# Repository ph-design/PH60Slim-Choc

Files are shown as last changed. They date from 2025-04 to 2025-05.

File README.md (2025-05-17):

### English Ver. | [中文](README-ZH.md)
---
# PH60 Slim-Choc  


**PH60 Slim-Choc is a 60% ANSI layout low-profile mechanical keyboard designed for portability and customization.**  
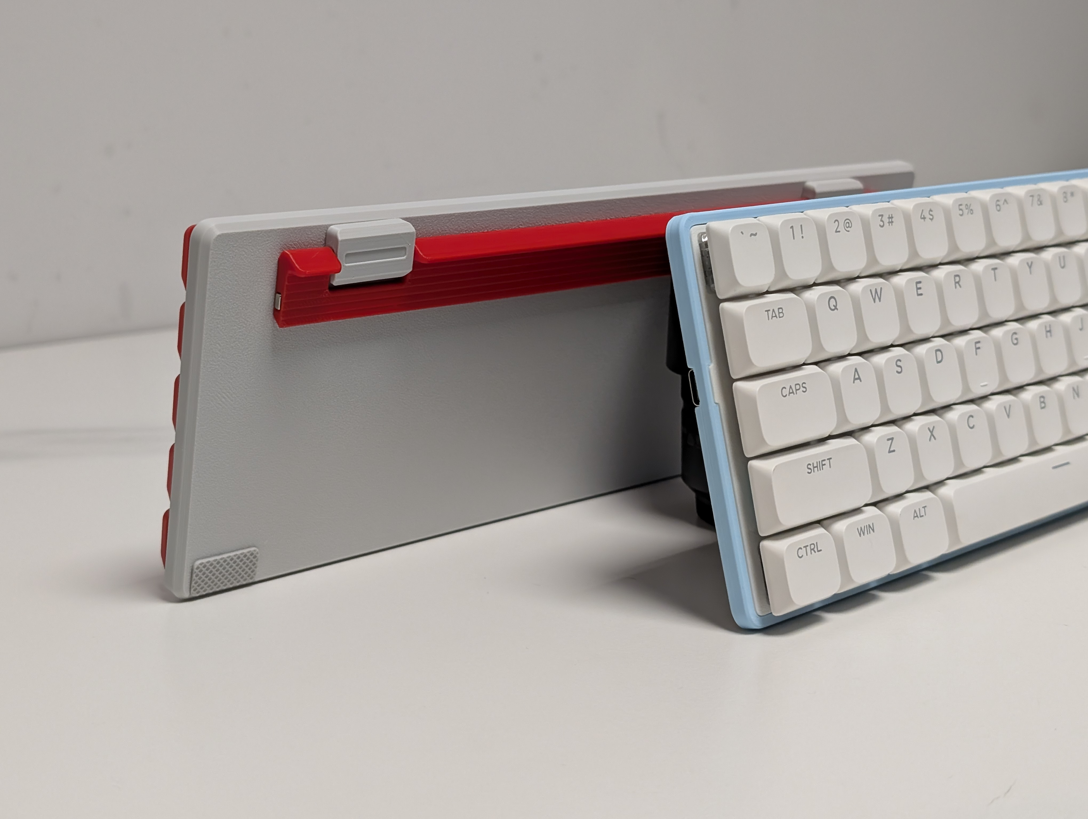
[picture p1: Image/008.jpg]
PH60Slim-Choc main frame


---

## Table of Contents
- [PH60 Slim-Choc](#ph60-slim-choc)
  - [Table of Contents](#table-of-contents)
  - [Features](#features)
  - [Required Components](#required-components)
  - [Printing Guide](#printing-guide)
    - [Case](#case)
    - [Keycaps](#keycaps)
  - [Assembly Guide](#assembly-guide)
  - [Firmware \& Configuration (WIP)](#firmware--configuration-wip)
    - [QMK/VIA Setup](#qmkvia-setup)
  - [Contributing](#contributing)
  - [FAQ](#faq)
  - [Special thanks](#special-thanks)
  - [Links](#links)
  - [License](#license)
  - [Changelog](#changelog)

---

## Features
+ 📏 **Ultra-Slim Design**: 7mm physical front height (4.5mm visual)
+ 🧲 **Adjustable Typing Angle**: Magnetic 2-step foldable footstand (5° and 10°)
+ 💻 **Laptop-Friendly**: Side-out USB-C for seamless laptop integration
+ 🔅 **Hotswap Ready**: Kailh Choc V1/V2 low-profile switches
+ 🖨️ **Easy Manufacturing**: Optimized for 3D printing/CNC
+ ⚡ **QMK & VIA Support**: Fully programmable with open-source firmware

---

## Required Components
| Part Name | Amount | Remark |
|---|---|---|
| PH60Slim-Choc PCB | 1 | Purchase in our Taobao Store (optional) |
| M2×2×3 Heat-Set Inserts | 10 | For securing case components |
| M2×3 Flat Head Screws | 4 | Footstand mounting |
| M2×5 Flat Head Screws | 6 | Case assembly |
| 20×10×0.5mm Ferrous Plate | 1 | Magnet alignment |
| 10×4×2mm N52 Magnet | 1 | Footstand retention |
| Low-Profile Stabilizers | 5 | 4×2u + 1×6.25u |
| Kailh Choc Switches | 61 | Compatible with Choc V1/V2 |
| Case Components | 1 set  | Includes bottom case, footstand, plate |
| Keycaps | 61 | DSA height recommended |

---

## Printing Guide
Slim-Choc components are optimized for Bambu Lab printers. However, they can also be printed with other printers by adjusting some of the parameters as follow:
### Case
- **Printing Profile**: [MakerWorld](https://makerworld.com/en/models/1361888)
- **Filament**: PLA 
- **Layer Height**: 0.16mm (0.2mm acceptable)
- **Walls**: 4 loops, Arachne wall generator
- **Infill**: 100% 
- **Supports**: Tree (auto)

### Keycaps
- **Printing Profile**: Follow [MakerWorld](https://makerworld.com/en/models/1394378)
- **Filament**: PETG

---

## Assembly Guide
1. **Heat-Set Inserts**  
   - Use soldering iron at 200°C to install inserts (8 in case, 4 in footstand).  
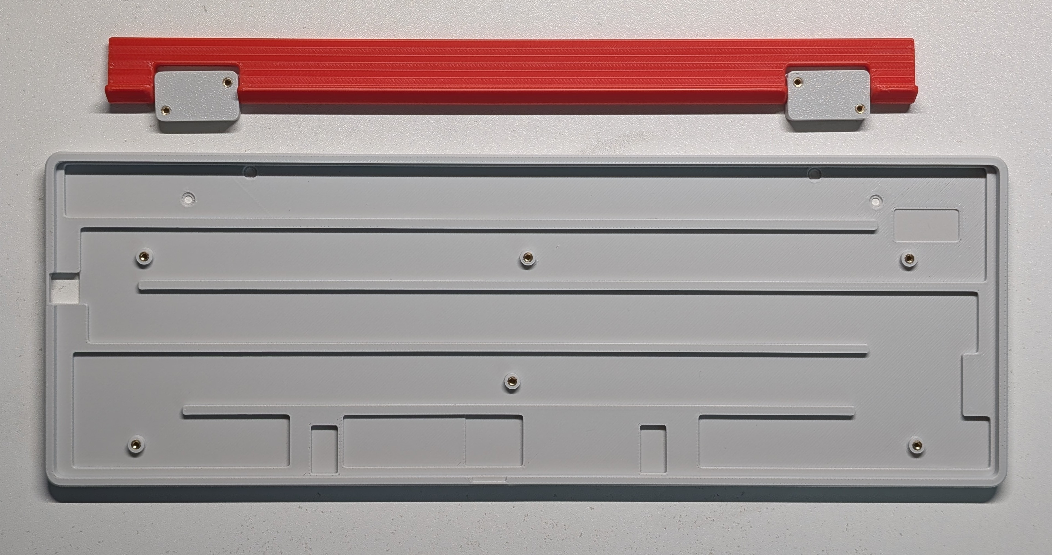
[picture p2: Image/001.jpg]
Heat insert installation
   

2. **Magnet Installation**  
   - Press-fit N52 magnet into footstand recess.  
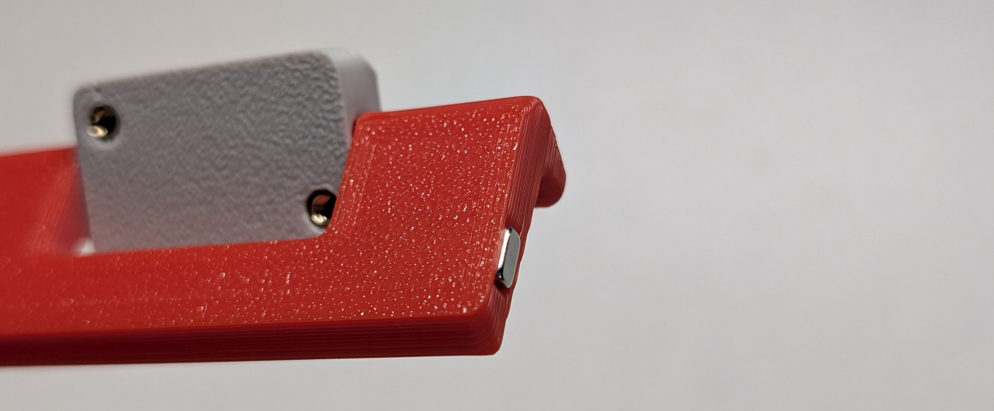
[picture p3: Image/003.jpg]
Magnet placement
   

3. **Footstand Assembly**  
   - Secure with M2×3 screws. Ensure smooth angular adjustment.  
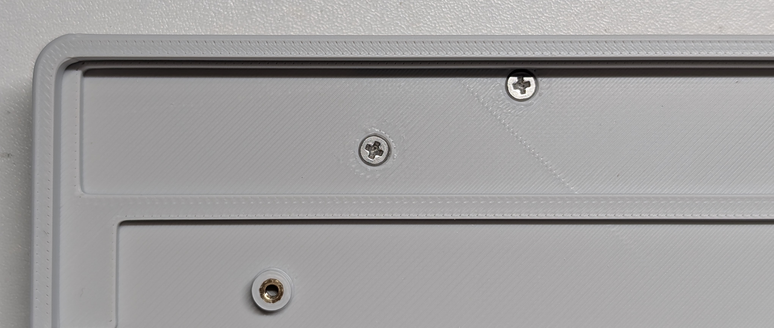
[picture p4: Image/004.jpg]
Footstand screws
   

4. **Ferrous Plate Attachment**  
   - Apply glue and insert an iron piece into the case. 
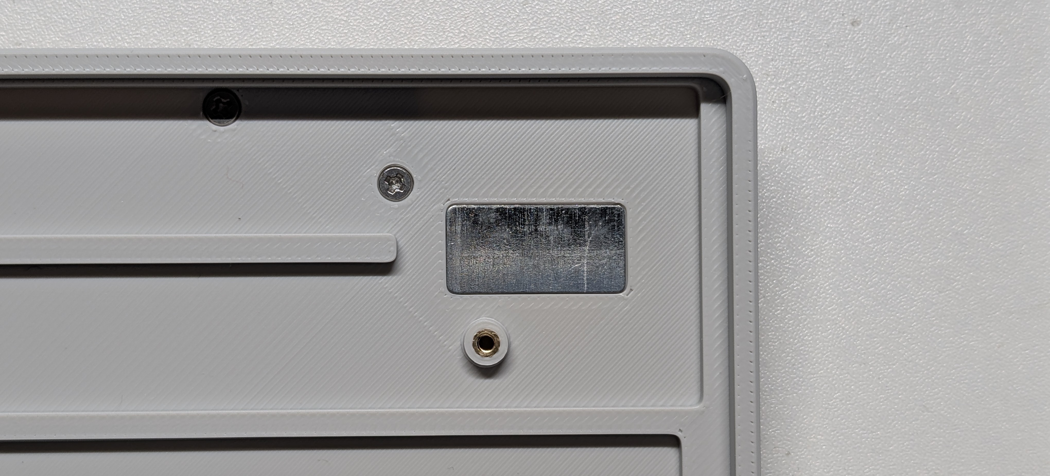
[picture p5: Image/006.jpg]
Steel plate installation
   

5. **Anti-Slip Pads**  
   - Apply silicone pads to case corners.  
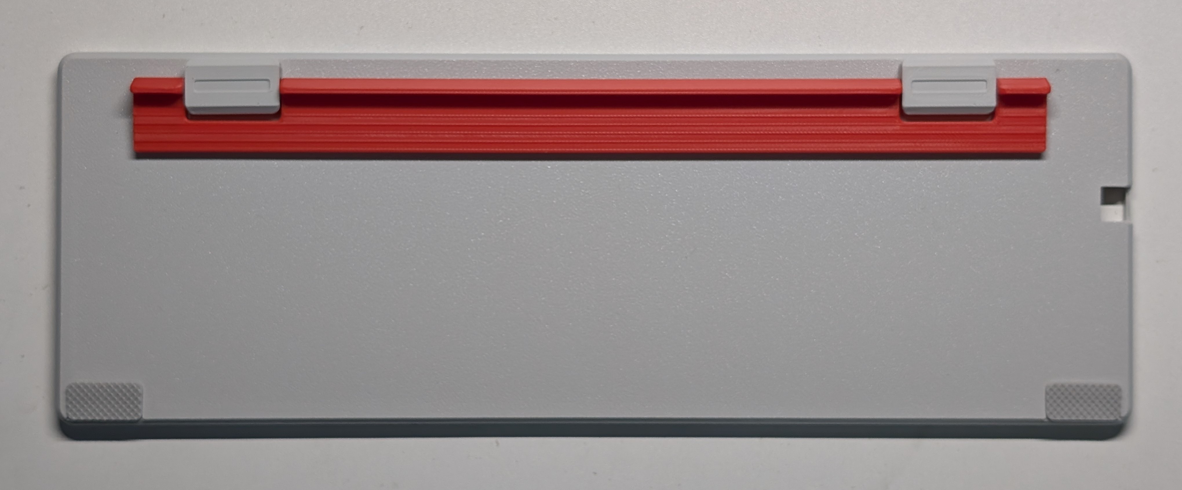
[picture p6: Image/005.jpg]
Silicone pads
   

6. **PCB & Plate Integration**  
   - Align plate with PCB, insert stabilizers and switches partially, then mount to case with M2×5 screws (torque evenly).  

7. **Final Assembly**  
   - Fully seat switches, test connectivity, then install keycaps.
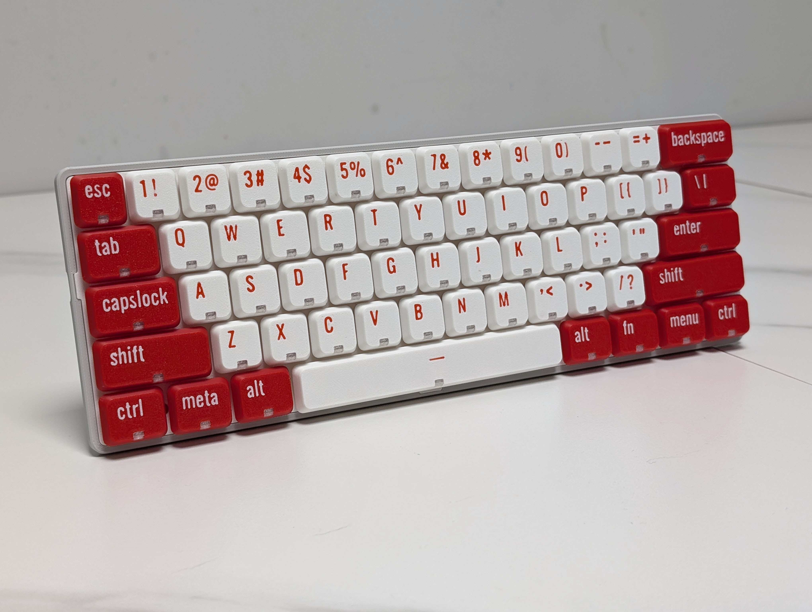
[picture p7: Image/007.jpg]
PCB assembly
   

---

## Firmware & Configuration (WIP)
### QMK/VIA Setup
1. **Compile from Source**:  
   ```bash
   qmk compile -kb phdesign/ph60slim_choc -km via
   ```
2. **Flashing**:  
  Shorten the boot perforations around the space with a metal object, plug in the USB cable, and drag the firmware into the USB drive that appears.

1. **Keymap Editor**:  
   Configure directly via [VIA Web](https://usevia.app/)

---

## Contributing
We welcome contributions! Please:  
1. Fork the repository
2. Create a feature branch
3. Submit PR with detailed description  

**Guidelines**:  
- Follow QMK coding standards for firmware  
- Include STEP files for hardware modifications  
- A dedicated documentation website will be available soon.

---

## FAQ
**Q: What switches can I use?**  
A: **ONLY** Kailh Choc switch, not Gateron or Cherry.

**Q: Where can I get the special stabilizer?**  
A: It can be found on Taobao, or modify the mounting plate to use Kailh official stabilizer (Not verified).

**Q: USB-C port not detected?**  
A: Ensure proper alignment of side-out connector with case cutout.

**Q: Recommended keycap?**  
A: Special low-profile keycaps are required. You can try our 3D-printed keycaps alternatively.

---

## Special thanks
- QMK Community for firmware support
- Bambu Lab for 3D printing support

---

## Links
- [GitHub Repository](https://github.com/ph-design/PH60Slim-Choc) 
- [Discord Community](https://discord.gg/8UfQXcefPH)
- [Build Video (Bilibili)](https://www.bilibili.com/video/BV1Te5VzBEiK/)
- [Purchase link (Taobao)](https://shop268559013.taobao.com/)
- [3D Printing Profiles](https://makerworld.com/en/@M_Altmann)
- [Official Website](https://phdesign.cc)

---

## License
This project is licensed under the [CC BY-NC-SA 4.0](https://creativecommons.org/licenses/by-nc-sa/4.0/) license.

---

## Changelog
- **2025-05-10**: Initial release.

---

*Project maintained by ph.design Released: 2025.05 


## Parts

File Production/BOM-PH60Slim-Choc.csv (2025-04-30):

Comment | Designator | Footprint | LCSC | Quantity
Choc_V1V2 | S20 | SW_Hotswap_Kailh_Choc_V1V2_Plated_1.00u |  | 1
Choc_V1V2 | S19 | SW_Hotswap_Kailh_Choc_V1V2_Plated_1.00u |  | 1
Choc_V1V2 | S47 | SW_Hotswap_Kailh_Choc_V1V2_Plated_1.00u |  | 1
Choc_V1V2 | S4 | SW_Hotswap_Kailh_Choc_V1V2_Plated_1.00u |  | 1
Choc_V1V2 | S7 | SW_Hotswap_Kailh_Choc_V1V2_Plated_1.00u |  | 1
Choc_V1V2 | S12 | SW_Hotswap_Kailh_Choc_V1V2_Plated_1.00u |  | 1
Choc_V1V2 | S62 | SW_Hotswap_Kailh_Choc_V1V2_Plated_1.25u |  | 1
Choc_V1V2 | S3 | SW_Hotswap_Kailh_Choc_V1V2_Plated_1.00u |  | 1
MountingHole | H4 | MountingHole_2.2mm_M2 |  | 1
Choc_V1V2 | S15 | SW_Hotswap_Kailh_Choc_V1V2_Plated_1.50u |  | 1
Choc_V1V2 | S25 | SW_Hotswap_Kailh_Choc_V1V2_Plated_1.00u |  | 1
Choc_V1V2 | S1 | SW_Hotswap_Kailh_Choc_V1V2_Plated_1.00u |  | 1
Choc_V1V2 | S9 | SW_Hotswap_Kailh_Choc_V1V2_Plated_1.00u |  | 1
Choc_V1V2 | S23 | SW_Hotswap_Kailh_Choc_V1V2_Plated_1.00u |  | 1
Choc_V1V2 | S57 | SW_Hotswap_Kailh_Choc_V1V2_Plated_1.25u |  | 1
Choc_V1V2 | S14 | SW_Hotswap_Kailh_Choc_V1V2_Plated_2.00u |  | 1
Choc_V1V2 | S61 | SW_Hotswap_Kailh_Choc_V1V2_Plated_1.25u |  | 1
Choc_V1V2 | S16 | SW_Hotswap_Kailh_Choc_V1V2_Plated_1.00u |  | 1
Choc_V1V2 | S24 | SW_Hotswap_Kailh_Choc_V1V2_Plated_1.00u |  | 1
Choc_V1V2 | S31 | SW_Hotswap_Kailh_Choc_V1V2_Plated_1.00u |  | 1
Choc_V1V2 | S33 | SW_Hotswap_Kailh_Choc_V1V2_Plated_1.00u |  | 1
Choc_V1V2 | S34 | SW_Hotswap_Kailh_Choc_V1V2_Plated_1.00u |  | 1
Choc_V1V2 | S46 | SW_Hotswap_Kailh_Choc_V1V2_Plated_1.00u |  | 1
MountingHole | H5 | MountingHole_2.2mm_M2 |  | 1
Choc_V1V2 | S50 | SW_Hotswap_Kailh_Choc_V1V2_Plated_1.00u |  | 1
Choc_V1V2 | S22 | SW_Hotswap_Kailh_Choc_V1V2_Plated_1.00u |  | 1
MountingHole | H1 | MountingHole_2.2mm_M2 |  | 1
Choc_V1V2 | S27 | SW_Hotswap_Kailh_Choc_V1V2_Plated_1.00u |  | 1
Choc_V1V2 | S58 | SW_Hotswap_Kailh_Choc_V1V2_Plated_1.25u |  | 1
Choc_V1V2 | S8 | SW_Hotswap_Kailh_Choc_V1V2_Plated_1.00u |  | 1
Choc_V1V2 | S63 | SW_Hotswap_Kailh_Choc_V1V2_Plated_1.25u |  | 1
Choc_V1V2 | S37 | SW_Hotswap_Kailh_Choc_V1V2_Plated_1.00u |  | 1
Choc_V1V2 | S21 | SW_Hotswap_Kailh_Choc_V1V2_Plated_1.00u |  | 1
Choc_V1V2 | S11 | SW_Hotswap_Kailh_Choc_V1V2_Plated_1.00u |  | 1
Choc_V1V2 | S52 | SW_Hotswap_Kailh_Choc_V1V2_Plated_1.00u |  | 1
Choc_V1V2 | S30 | SW_Hotswap_Kailh_Choc_V1V2_Plated_1.00u |  | 1
Choc_V1V2 | S38 | SW_Hotswap_Kailh_Choc_V1V2_Plated_1.00u |  | 1
Choc_V1V2 | S35 | SW_Hotswap_Kailh_Choc_V1V2_Plated_1.00u |  | 1
Choc_V1V2 | S39 | SW_Hotswap_Kailh_Choc_V1V2_Plated_1.00u |  | 1
Choc_V1V2 | S48 | SW_Hotswap_Kailh_Choc_V1V2_Plated_1.00u |  | 1
Choc_V1V2 | S18 | SW_Hotswap_Kailh_Choc_V1V2_Plated_1.00u |  | 1
Choc_V1V2 | S41-2 | SW_Hotswap_Kailh_Choc_V1V2_Plated_2.25u |  | 1
Choc_V1V2 | S45 | SW_Hotswap_Kailh_Choc_V1V2_Plated_1.00u |  | 1
Choc_V1V2 | S13 | SW_Hotswap_Kailh_Choc_V1V2_Plated_1.00u |  | 1
Choc_V1V2 | S26 | SW_Hotswap_Kailh_Choc_V1V2_Plated_1.00u |  | 1
Choc_V1V2 | S5 | SW_Hotswap_Kailh_Choc_V1V2_Plated_1.00u |  | 1
Choc_V1V2 | S17 | SW_Hotswap_Kailh_Choc_V1V2_Plated_1.00u |  | 1
Choc_V1V2 | S32 | SW_Hotswap_Kailh_Choc_V1V2_Plated_1.00u |  | 1
Choc_V1V2 | S55-2 | SW_Hotswap_Kailh_Choc_V1V2_Plated_2.75u |  | 1
Choc_V1V2 | S36 | SW_Hotswap_Kailh_Choc_V1V2_Plated_1.00u |  | 1
Choc_V1V2 | S49 | SW_Hotswap_Kailh_Choc_V1V2_Plated_1.00u |  | 1
Choc_V1V2 | S60 | SW_Hotswap_Kailh_Choc_V1V2_Plated_6.25u |  | 1
Choc_V1V2 | S53 | SW_Hotswap_Kailh_Choc_V1V2_Plated_1.00u |  | 1
Choc_V1V2 | S10 | SW_Hotswap_Kailh_Choc_V1V2_Plated_1.00u |  | 1
MountingHole | H6 | MountingHole_2.2mm_M2 |  | 1
Choc_V1V2 | S59 | SW_Hotswap_Kailh_Choc_V1V2_Plated_1.25u |  | 1
Choc_V1V2 | S54 | SW_Hotswap_Kailh_Choc_V1V2_Plated_1.00u |  | 1
Choc_V1V2 | S51 | SW_Hotswap_Kailh_Choc_V1V2_Plated_1.00u |  | 1
Choc_V1V2 | S28-2 | SW_Hotswap_Kailh_Choc_V1V2_Plated_1.50u |  | 1
Choc_V1V2 | S29 | SW_Hotswap_Kailh_Choc_V1V2_Plated_1.75u |  | 1
Choc_V1V2 | S6 | SW_Hotswap_Kailh_Choc_V1V2_Plated_1.00u |  | 1
MountingHole | H2 | MountingHole_2.2mm_M2 |  | 1
Choc_V1V2 | S43-2 | SW_Hotswap_Kailh_Choc_V1V2_Plated_2.25u |  | 1
Choc_V1V2 | S2 | SW_Hotswap_Kailh_Choc_V1V2_Plated_1.00u |  | 1
MountingHole | H3 | MountingHole_2.2mm_M2 |  | 1
Choc_V1V2 | S64 | SW_Hotswap_Kailh_Choc_V1V2_Plated_1.25u |  | 1
Choc_V1V2 | S40 | SW_Hotswap_Kailh_Choc_V1V2_Plated_1.00u |  | 1
DIODE | D1 | D_SOD-123 |  | 1
WS2812B | RGB15 | ws2812B_6028_FIX |  | 1
WS2812B | RGB9 | ws2812B_6028_FIX |  | 1
WS2812B | RGB56 | ws2812B_6028_FIX |  | 1
WS2812B | RGB2 | ws2812B_6028_FIX |  | 1
PRTR5V0U2X | D65 | SOT-143 |  | 1
DIODE | D46 | D_SOD-123 |  | 1
DIODE | D32 | D_SOD-123 |  | 1
DIODE | D34 | D_SOD-123 |  | 1
WS2812B | RGB29 | ws2812B_6028_FIX |  | 1
WS2812B | RGB16 | ws2812B_6028_FIX |  | 1
WS2812B | RGB12 | ws2812B_6028_FIX |  | 1
DIODE | D41 | D_SOD-123 |  | 1
WS2812B | RGB37 | ws2812B_6028_FIX |  | 1
DIODE | D50 | D_SOD-123 |  | 1
DIODE | D51 | D_SOD-123 |  | 1
DIODE | D5 | D_SOD-123 |  | 1
WS2812B | RGB8 | ws2812B_6028_FIX |  | 1
WS2812B | RGB44 | ws2812B_6028_FIX |  | 1
1k | R1 | R_0402_1005Metric |  | 1
DIODE | D38 | D_SOD-123 |  | 1
WS2812B | RGB19 | ws2812B_6028_FIX |  | 1
DIODE | D52 | D_SOD-123 |  | 1
DIODE | D60 | D_SOD-123 |  | 1
DIODE | D48 | D_SOD-123 |  | 1
DIODE | D20 | D_SOD-123 |  | 1
1u | C8 | C_0402_1005Metric |  | 1
DIODE | D55 | D_SOD-123 |  | 1
DIODE | D49 | D_SOD-123 |  | 1
WS2812B | RGB43 | ws2812B_6028_FIX |  | 1
DIODE | D64 | D_SOD-123 |  | 1
DIODE | D27 | D_SOD-123 |  | 1
WS2812B | RGB46 | ws2812B_6028_FIX |  | 1
1u | C10 | C_0402_1005Metric |  | 1
DIODE | D3 | D_SOD-123 |  | 1
WS2812B | RGB40 | ws2812B_6028_FIX |  | 1
WS2812B | RGB33 | ws2812B_6028_FIX |  | 1
5K1 | R6 | R_0402_1005Metric |  | 1
DIODE | D4 | D_SOD-123 |  | 1
DIODE | D33 | D_SOD-123 |  | 1
WS2812B | RGB24 | ws2812B_6028_FIX |  | 1
100n | C9 | C_0402_1005Metric |  | 1
100n | C7 | C_0402_1005Metric |  | 1
DIODE | D17 | D_SOD-123 |  | 1
WS2812B | RGB4 | ws2812B_6028_FIX |  | 1
Crystal_GND24 | Y1 | Crystal_SMD_3225-4Pin_3.2x2.5mm |  | 1
W25Q128JVS | U2 | Winbond_USON-8-1EP_3x2mm_P0.5mm_EP0.2x1.6mm |  | 1
20p | C2 | C_0402_1005Metric |  | 1
WS2812B | RGB21 | ws2812B_6028_FIX |  | 1
WS2812B | RGB48 | ws2812B_6028_FIX |  | 1
1R | R4 | R_0402_1005Metric |  | 1
DIODE | D28 | D_SOD-123 |  | 1
WS2812B | RGB58 | ws2812B_6028_FIX |  | 1
WS2812B | RGB10 | ws2812B_6028_FIX |  | 1
WS2812B | RGB6 | ws2812B_6028_FIX |  | 1
DIODE | D63 | D_SOD-123 |  | 1
DIODE | D31 | D_SOD-123 |  | 1
WS2812B | RGB20 | ws2812B_6028_FIX |  | 1
RP2040 | U3 | QFN-56-1EP_7x7mm_P0.4mm_EP3.2x3.2mm |  | 1
WS2812B | RGB50 | ws2812B_6028_FIX |  | 1
1u | C4 | C_0402_1005Metric |  | 1
DIODE | D29 | D_SOD-123 |  | 1
DIODE | D40 | D_SOD-123 |  | 1
WS2812B | RGB5 | ws2812B_6028_FIX |  | 1
WS2812B | RGB49 | ws2812B_6028_FIX |  | 1
WS2812B | RGB7 | ws2812B_6028_FIX |  | 1
DIODE | D47 | D_SOD-123 |  | 1
DIODE | D9 | D_SOD-123 |  | 1
1k | R5 | R_0402_1005Metric |  | 1
DIODE | D45 | D_SOD-123 |  | 1
DIODE | D54 | D_SOD-123 |  | 1
WS2812B | RGB3 | ws2812B_6028_FIX |  | 1
DIODE | D7 | D_SOD-123 |  | 1
DIODE | D53 | D_SOD-123 |  | 1
DIODE | D24 | D_SOD-123 |  | 1
WS2812B | RGB45 | ws2812B_6028_FIX |  | 1
100n | C12 | C_0402_1005Metric |  | 1
WS2812B | RGB51 | ws2812B_6028_FIX |  | 1
WS2812B | RGB55 | ws2812B_6028_FIX |  | 1
DIODE | D39 | D_SOD-123 |  | 1
WS2812B | RGB34 | ws2812B_6028_FIX |  | 1
WS2812B | RGB26 | ws2812B_6028_FIX |  | 1
WS2812B | RGB59 | ws2812B_6028_FIX |  | 1
DIODE | D21 | D_SOD-123 |  | 1
20p | C3 | C_0402_1005Metric |  | 1
WS2812B | RGB54 | ws2812B_6028_FIX |  | 1
WS2812B | RGB38 | ws2812B_6028_FIX |  | 1
WS2812B | RGB1 | ws2812B_6028_FIX |  | 1
DIODE | D10 | D_SOD-123 |  | 1
Conn_01x02 | J2 | PinHeader_1x02_P1.27mm_Vertical |  | 1
WS2812B | RGB11 | ws2812B_6028_FIX |  | 1
WS2812B | RGB32 | ws2812B_6028_FIX |  | 1
DIODE | D2 | D_SOD-123 |  | 1
DIODE | D25 | D_SOD-123 |  | 1
WS2812B | RGB31 | ws2812B_6028_FIX |  | 1
WS2812B | RGB18 | ws2812B_6028_FIX |  | 1
WS2812B | RGB52 | ws2812B_6028_FIX |  | 1
DIODE | D14 | D_SOD-123 |  | 1
DIODE | D57 | D_SOD-123 |  | 1
WS2812B | RGB42 | ws2812B_6028_FIX |  | 1
DIODE | D16 | D_SOD-123 |  | 1
1u | C1 | C_0402_1005Metric |  | 1
DIODE | D13 | D_SOD-123 |  | 1
500ma | F1 | Fuse_0603_1608Metric |  | 1
DIODE | D43 | D_SOD-123 |  | 1
WS2812B | RGB14 | ws2812B_6028_FIX |  | 1
XC6206PxxxMR | U4 | SOT-23-3 |  | 1
WS2812B | RGB27 | ws2812B_6028_FIX |  | 1
WS2812B | RGB41 | ws2812B_6028_FIX |  | 1
DIODE | D15 | D_SOD-123 |  | 1
WS2812B | RGB57 | ws2812B_6028_FIX |  | 1
DIODE | D6 | D_SOD-123 |  | 1
WS2812B | RGB60 | ws2812B_6028_FIX |  | 1
100n | C11 | C_0402_1005Metric |  | 1
100n | C16 | C_0402_1005Metric |  | 1
DIODE | D59 | D_SOD-123 |  | 1
DIODE | D26 | D_SOD-123 |  | 1
WS2812B | RGB22 | ws2812B_6028_FIX |  | 1
WS2812B | RGB28 | ws2812B_6028_FIX |  | 1
DIODE | D18 | D_SOD-123 |  | 1
WS2812B | RGB39 | ws2812B_6028_FIX |  | 1
DIODE | D62 | D_SOD-123 |  | 1
100n | C13 | C_0402_1005Metric |  | 1
DIODE | D23 | D_SOD-123 |  | 1
WS2812B | RGB17 | ws2812B_6028_FIX |  | 1
DIODE | D36 | D_SOD-123 |  | 1
WS2812B | RGB25 | ws2812B_6028_FIX |  | 1
DIODE | D58 | D_SOD-123 |  | 1
WS2812B | RGB47 | ws2812B_6028_FIX |  | 1
DIODE | D37 | D_SOD-123 |  | 1
DIODE | D12 | D_SOD-123 |  | 1
5K1 | R7 | R_0402_1005Metric |  | 1
DIODE | D35 | D_SOD-123 |  | 1
DIODE | D30 | D_SOD-123 |  | 1
100n | C6 | C_0402_1005Metric |  | 1
DIODE | D22 | D_SOD-123 |  | 1
WS2812B | RGB36 | ws2812B_6028_FIX |  | 1
DIODE | D61 | D_SOD-123 |  | 1
WS2812B | RGB53 | ws2812B_6028_FIX |  | 1
WS2812B | RGB23 | ws2812B_6028_FIX |  | 1
100n | C14 | C_0402_1005Metric |  | 1
WS2812B | RGB61 | ws2812B_6028_FIX |  | 1
DIODE | D11 | D_SOD-123 |  | 1
WS2812B | RGB13 | ws2812B_6028_FIX |  | 1
100n | C15 | C_0402_1005Metric |  | 1
DIODE | D19 | D_SOD-123 |  | 1
1R | R3 | R_0402_1005Metric |  | 1
WS2812B | RGB30 | ws2812B_6028_FIX |  | 1
USB_C_Receptacle_USB2.0_16P | J1 | USB_C_Receptacle_GCT_USB4105-xx-A_16P_TopMnt_Horizontal |  | 1
DIODE | D8 | D_SOD-123 |  | 1
WS2812B | RGB35 | ws2812B_6028_FIX |  | 1
100n | C5 | C_0402_1005Metric |  | 1

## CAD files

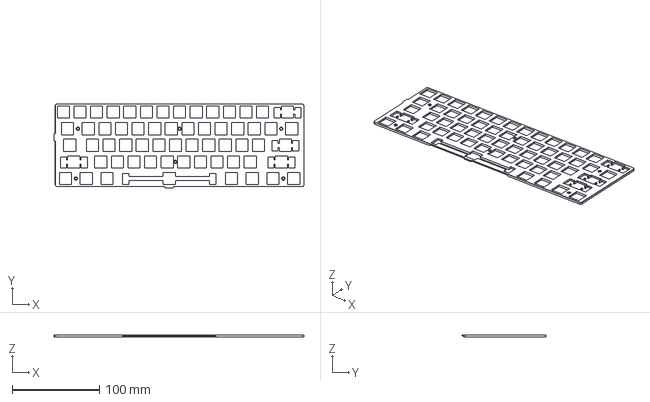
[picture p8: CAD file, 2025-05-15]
Model/Case/plate.step
286.9 x 96.5 x 2.40 mm

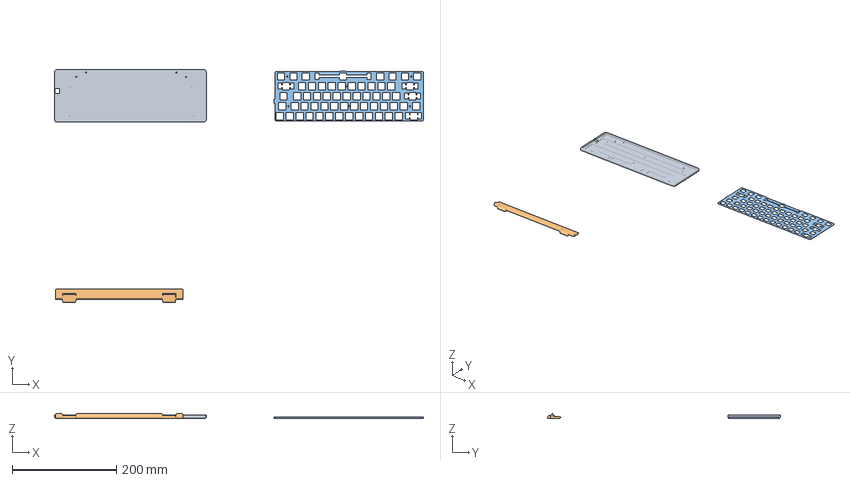
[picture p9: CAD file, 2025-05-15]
Production/Slim-Choc Case(Bambu Studio).3mf
708.7 x 447.2 x 9.36 mm
PH60/Multi_Bottom
stand
PH60Slim_Plate

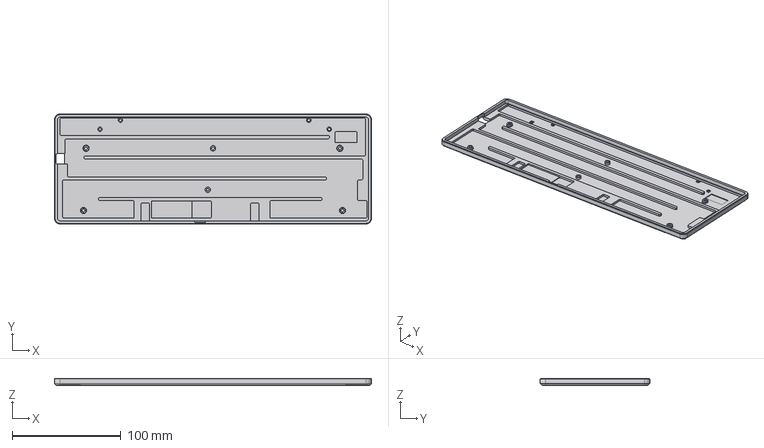
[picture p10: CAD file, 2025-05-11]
Model/Case/case.step
291.5 x 101.0 x 6.77 mm

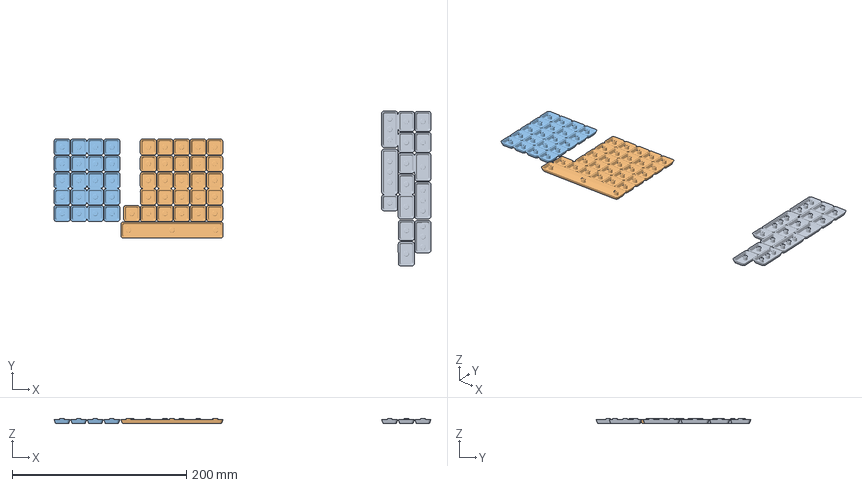
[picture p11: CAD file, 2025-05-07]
Production/Low Profile Keycaps(Bambu Studio).3mf
432.6 x 177.7 x 5.40 mm
FUN KEY
LETTER KEY
SYMB KEY

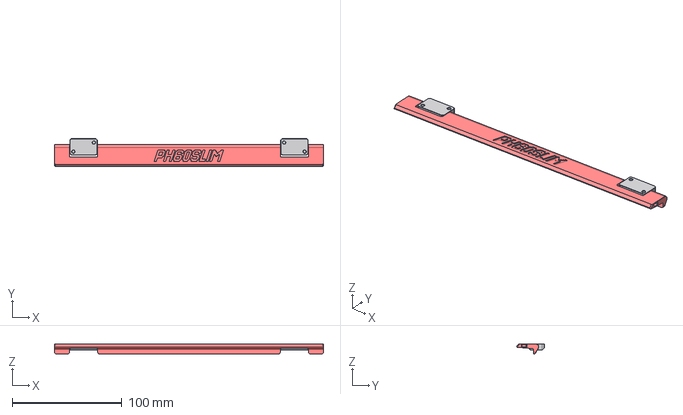
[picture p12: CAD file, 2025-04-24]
Model/Case/stand.step
245.0 x 25.4 x 9.36 mm

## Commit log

2025-04-24 Update license and 3D models
    + Switch to CC license
    + Add 3D models
    [PH60Slim_Choc.3mf, case.step, plate.step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]
2025-04-26 Add slicer file.
    + Add slicer file for BambuLab H2D.
    [For Bambu Studio.3mf]
2025-04-30 Fuse and silkscreen update.
    [PH60Slim-Choc.kicad_sch]
2025-05-07 Upload CAD and production files of keycaps
    [Low Profile Keycaps.3mf]
2025-05-10 Update README and production files
    [Low Profile Keycaps(Bambu Studio).3mf, PH60Slim_Choc.3mf, Slim-Choc Case(Bambu Studio).3mf]
2025-05-11 Fix a mounting issue and adjust the cut-out
    [Slim-Choc Case(Bambu Studio).3mf, case.step, plate.step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]
2025-05-15 Update mounitng plate and README
    [Slim-Choc Case(Bambu Studio).3mf, plate.step]

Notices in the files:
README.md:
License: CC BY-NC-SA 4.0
